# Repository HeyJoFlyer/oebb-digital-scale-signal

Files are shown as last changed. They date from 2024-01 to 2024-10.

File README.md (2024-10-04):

# ÖBB digital HV signal

## Description
This is an open-source project that provides detailed instructions for 
creating a 3D printed ÖBB (Austrian Federal Railways) signal model based 
on the [3d model](https://www.thingiverse.com/thing:6121234/files) of [Stubenflieger](https://www.thingiverse.com/stubenflieger/designs).

signal photo

## Features
- 3D printed model
- Multicolor sign
- Based on the work of Stubenflieger
- All signal states implemented in software
- G-Scale model, also useable as decoration

## Requirements
To create the ÖBB signal, you will need:
1. A 3D printer with the appropriate capabilities (multicolor not required, but helps for `4_Hauptsignal_Platte multicolor.3mf`)
1. 12 5mm leds: (5 green, 3 yellow, 1 red, 3 white)
1. Raspberry Pi Pico with [Circuitpython](https://circuitpython.org/board/raspberry_pi_pico/) (no extra libraries)
1. Resistors and wires and 2 buttons

## Instructions
1. Print 3d models, you can choose to print 
1. if you dont have the required color or dont have a multicolor 3d printer, you should paint the parts (photos), you can view the renders [here](/renders/renders.md).
1. Assembly parts (I used a 3d pen with same grey filament)
1. Under `test/code.py`you can find a test python script, where you will need to adjust the GP pins to your connected pins. With this script you can figure out which led is connected to which pin (took me ages without it), you can switch active led by pulling `GP0` low. You can view the output on the `REPL`using Thonny or MU editor.

## Acknowledgments
This open source project is based on the [work of Stubenflieger](https://www.thingiverse.com/thing:6121234/files).

## License
This project is licensed under the CC-BY-NC-4.0 License (as was Stubenfliegers design), following files are also available under the MIT License:
- `code.py`
- `test/cody.py`

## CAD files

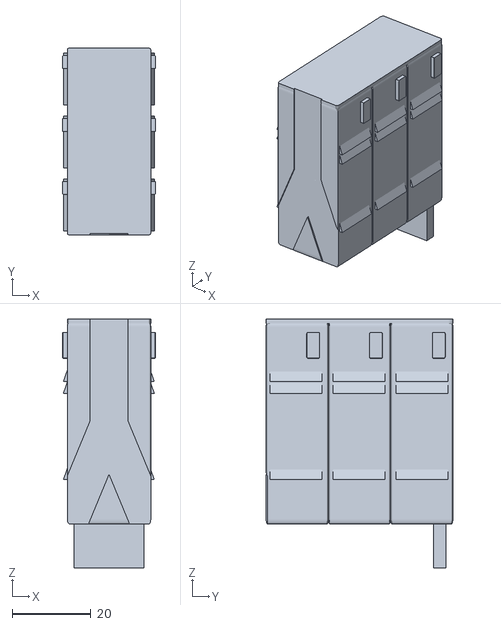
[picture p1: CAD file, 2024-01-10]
3a_Signalbox_gross.stl
23.6 x 47.6 x 63.4

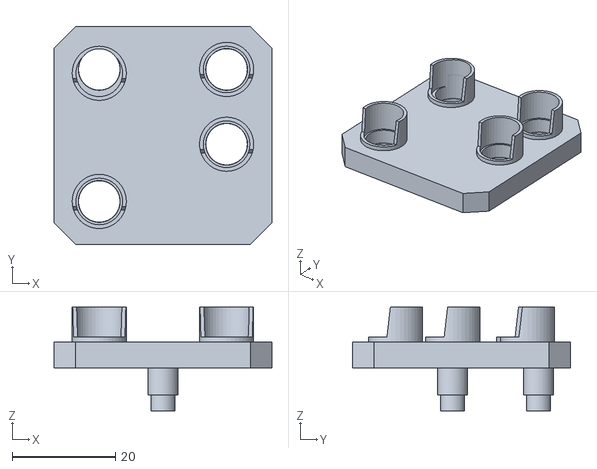
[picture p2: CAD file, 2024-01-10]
Vor_Signal_Spur_G.stl
42.2 x 42.2 x 20.1

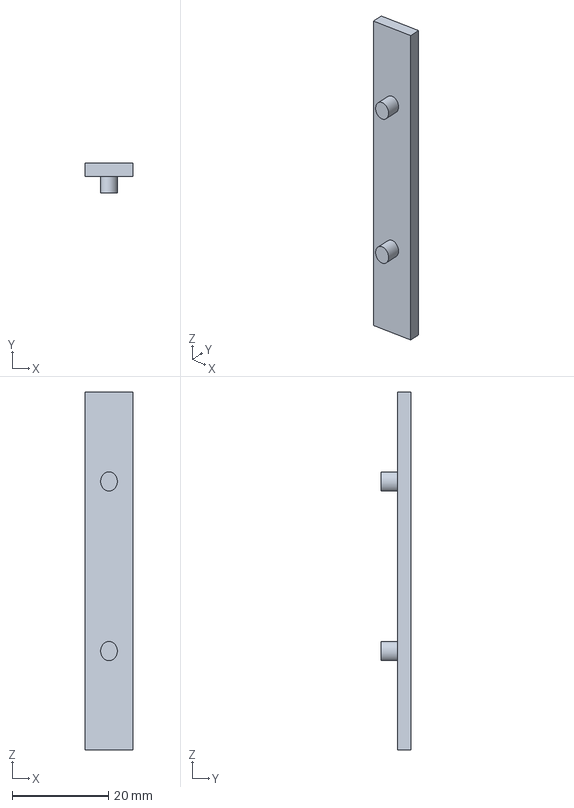
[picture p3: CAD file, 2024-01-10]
4_Hauptsignal_Platte multicolor.3mf
10.0 x 6.13 x 74.3 mm

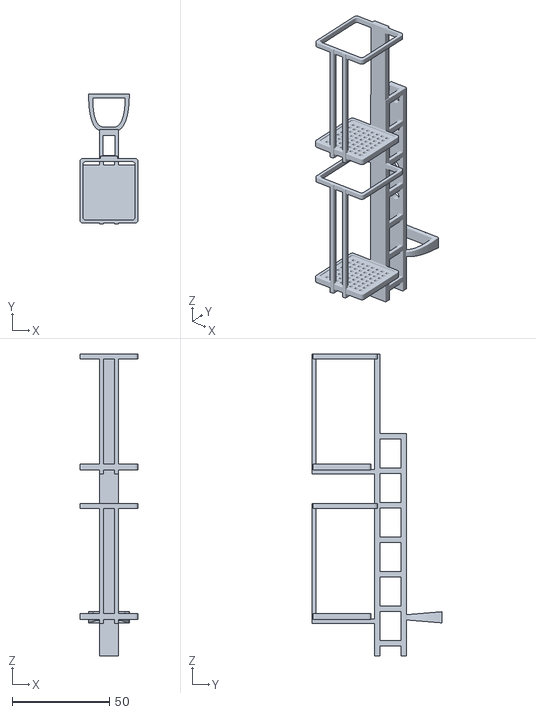
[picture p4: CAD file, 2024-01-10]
2a_Haupt_Vor_Signal_Spur_G_Mast_oben.stl
30.0 x 67.0 x 155.6

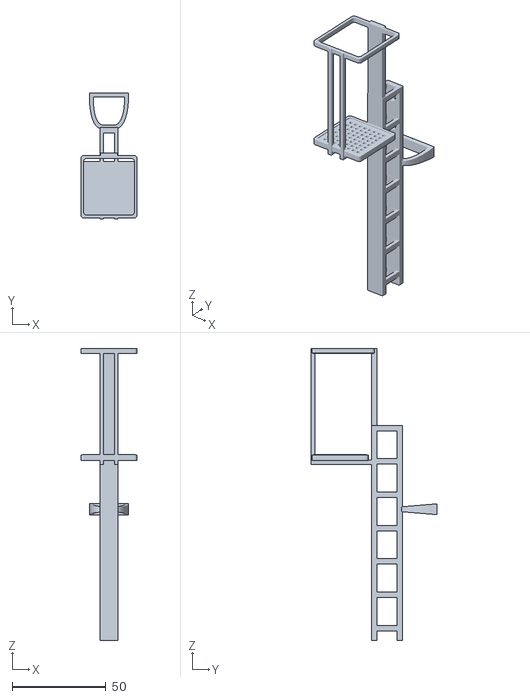
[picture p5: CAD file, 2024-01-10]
2b_Haupt_Signal_Spur_G_Mast_oben.stl
30.0 x 67.0 x 155.6

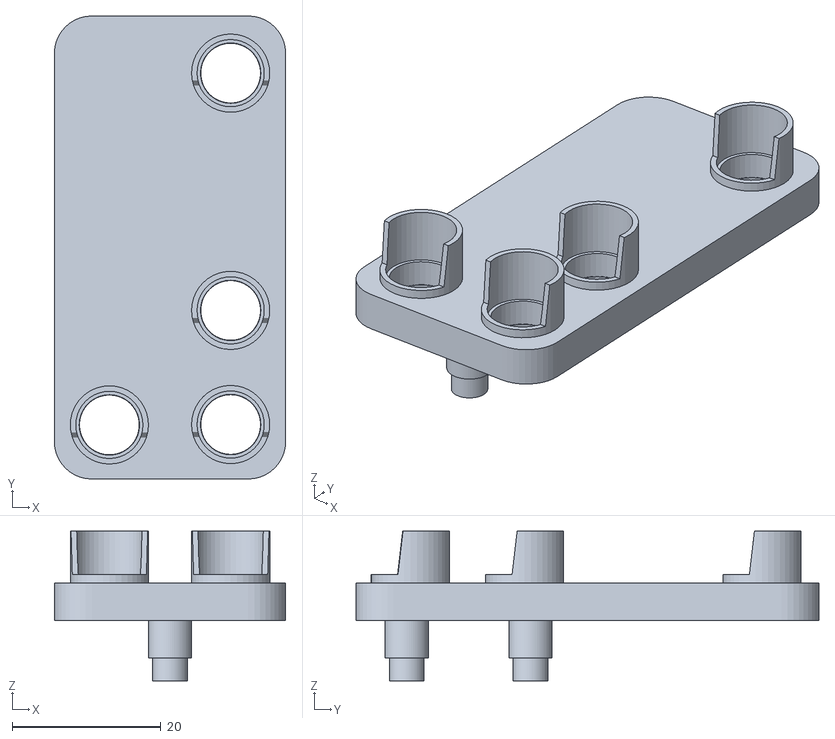
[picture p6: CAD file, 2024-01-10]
Hauptsignal_grosse_Lampen_Spur_G.stl
31.1 x 62.2 x 20.1

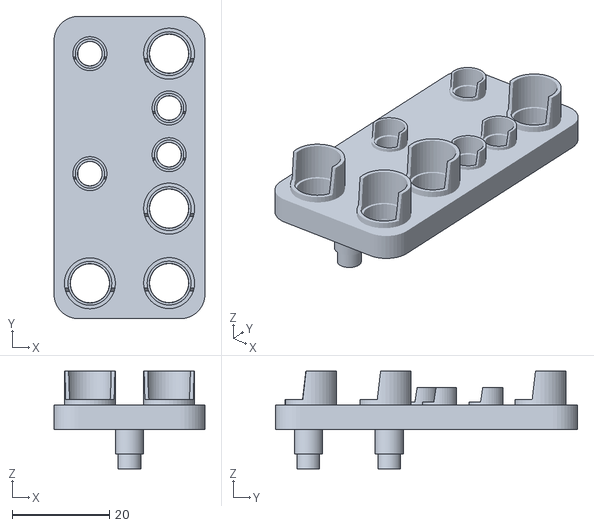
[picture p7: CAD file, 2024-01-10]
Hauptsignal_komplett_Spur_G.stl
31.1 x 62.2 x 20.1

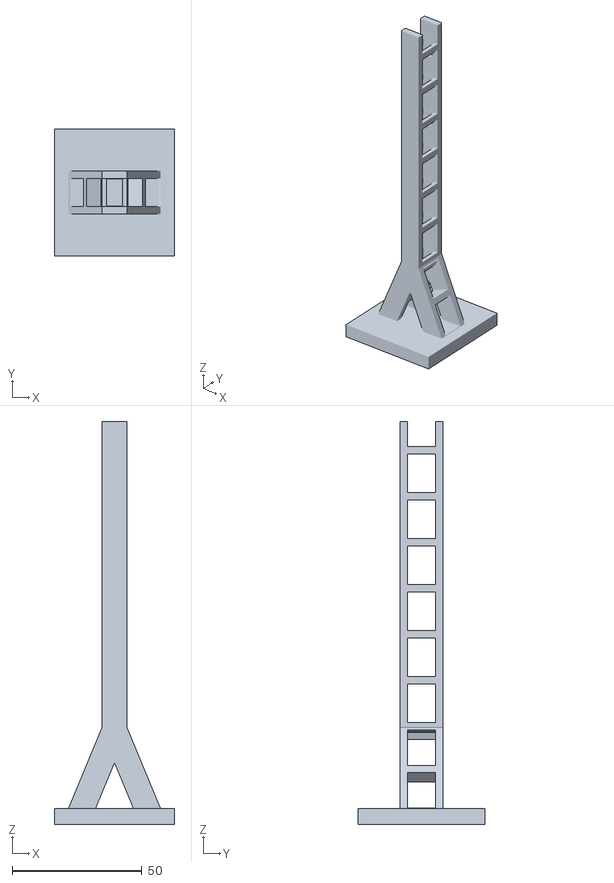
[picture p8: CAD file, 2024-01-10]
1_Haupt_Vor_Signal_Spur_G_Mast_unten.stl
46.4 x 49.1 x 155.6

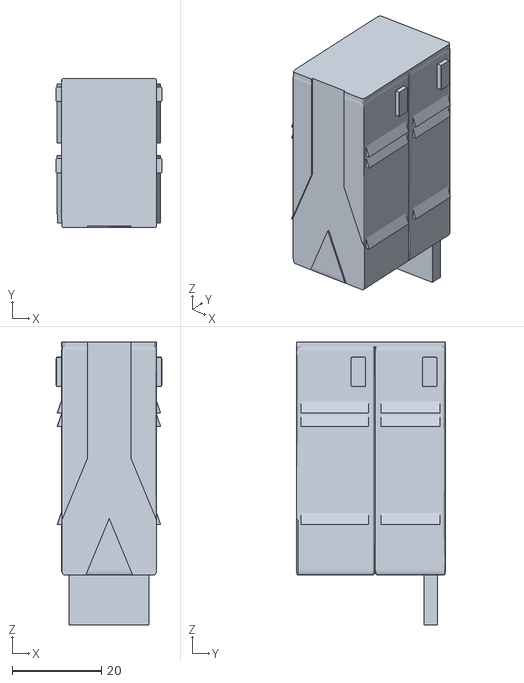
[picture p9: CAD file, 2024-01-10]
3b_Signalbox_klein.stl
23.6 x 33.5 x 63.4

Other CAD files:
4_Hauptsignal_Platte orig.stl

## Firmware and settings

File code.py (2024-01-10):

# SPDX-FileCopyrightText: 2024 Nico Gartner
#
# SPDX-License-Identifier: MIT
import board
import time
from digitalio import DigitalInOut, Direction, Pull

right_yellow_light = DigitalInOut(board.GP14)
left_yellow_light = DigitalInOut(board.GP12)
right_green_light = DigitalInOut(board.GP20)
left_green_light = DigitalInOut(board.GP18)

hp1_green_light = DigitalInOut(board.GP26)
hp2_green_light = DigitalInOut(board.GP13)
hp2_yellow_light = DigitalInOut(board.GP22)
hp0_red_light = DigitalInOut(board.GP17)
depature_green_light = DigitalInOut(board.GP19)
upper_white_light = DigitalInOut(board.GP15)
lower_white_light = DigitalInOut(board.GP21)
right_white_light = DigitalInOut(board.GP16)

right_yellow_light.direction = Direction.OUTPUT
left_yellow_light.direction = Direction.OUTPUT
right_green_light.direction = Direction.OUTPUT
left_green_light.direction = Direction.OUTPUT

hp1_green_light.direction = Direction.OUTPUT
hp2_green_light.direction = Direction.OUTPUT
hp2_yellow_light.direction = Direction.OUTPUT
hp0_red_light.direction = Direction.OUTPUT
depature_green_light.direction = Direction.OUTPUT
upper_white_light.direction = Direction.OUTPUT
lower_white_light.direction = Direction.OUTPUT
right_white_light.direction = Direction.OUTPUT

right_yellow_light.value = False
left_yellow_light.value = False
right_green_light.value = False
left_green_light.value = False

hp1_green_light.value = False
hp2_green_light.value = False
hp2_yellow_light.value = False
hp0_red_light.value = False
depature_green_light.value = False
upper_white_light.value = False
lower_white_light.value = False
right_white_light.value = False

button = DigitalInOut(board.GP0)
button.direction = Direction.INPUT
button.pull = Pull.UP

button_vor = DigitalInOut(board.GP1)
button_vor.direction = Direction.INPUT
button_vor.pull = Pull.UP

# (0, 0, 0, 0, 0, 0, 0, 0)
# (0, 0, 0, 0)

signalbegriffe = {"halt": (0, 0, 0, 1, 0, 0, 0, 0), "frei": (1, 0, 0, 0, 0, 0, 0, 0), "frei 60": (1, 1, 0, 0, 0, 0, 0, 0), "frei 40": (1, 0, 1, 0, 0, 0, 0, 0), "fahrverbot aufgehoben": (0, 0, 0, 0, 0, 1, 1, 0), "verschubverbot aufgehoben": (0, 0, 0, 1, 0, 0, 1, 1), "abfahren erlaubt": (1, 0, 0, 0, 2, 0, 0, 0), "ersatzsignal": (0, 0, 0, 1, 0, 2, 0, 0)}
vorsignalbegriffe = {"vorsicht": (1, 1, 0, 0), "hautpsignal frei": (0, 0, 1, 1), "hautpsignal frei 60": (0, 1, 1, 1), "hautpsignal frei 40": (1, 1, 0, 1), "abgeschaltet": (0, 0, 0, 0)}
signalbegriffe_keys = list(signalbegriffe.keys())
vorsignalbegriffe_keys = list(vorsignalbegriffe.keys())

def signal(signalbegriff_index, vorsignalbegriff_index):
    j = signalbegriffe_keys[signalbegriff_index]
    values = signalbegriffe[j]
    k = vorsignalbegriffe_keys[vorsignalbegriff_index]
    print(j, k)
    values_vor = vorsignalbegriffe[k]
    to_blink = []
    if values[0] == 1:
        hp1_green_light.value = True
    elif values[0] == 2:
        to_blink.append(hp1_green_light)
    else:
        hp1_green_light.value = False
    
    if values[1] == 1:
        hp2_green_light.value = True
    elif values[1] == 2:
        to_blink.append(hp2_green_light)
    else:
        hp2_green_light.value = False
    
    if values[2] == 1:
        hp2_yellow_light.value = True
    elif values[2] == 2:
        to_blink.append(hp2_yellow_light)
    else:
        hp2_yellow_light.value = False

    if values[3] == 1:
        hp0_red_light.value = True
    elif values[3] == 2:
        to_blink.append(hp0_red_light)
    else:
        hp0_red_light.value = False

    if values[4] == 1:
        depature_green_light.value = True
    elif values[4] == 2:
        to_blink.append(depature_green_light)
    else:
        depature_green_light.value = False

    if values[5] == 1:
        upper_white_light.value = True
    elif values[5] == 2:
        to_blink.append(upper_white_light)
    else:
        upper_white_light.value = False

    if values[6] == 1:
        lower_white_light.value = True
    elif values[6] == 2:
        to_blink.append(lower_white_light)
    else:
        lower_white_light.value = False

    if values[7] == 1:
        right_white_light.value = True
    elif values[7] == 2:
        to_blink.append(right_white_light)
    else:
        right_white_light.value = False

    if values_vor[0] == 1:
        right_yellow_light.value = True
    elif values_vor[0] == 2:
        to_blink.append(right_yellow_light)
    else:
        right_yellow_light.value = False

    if values_vor[1] == 1:
        left_yellow_light.value = True
    elif values_vor[1] == 2:
        to_blink.append(left_yellow_light)
    else:
        left_yellow_light.value = False

    if values_vor[2] == 1:
        right_green_light.value = True
    elif values_vor[2] == 2:
        to_blink.append(right_green_light)
    else:
       right_green_light.value = False

    if values_vor[3] == 1:
        left_green_light.value = True
    elif values_vor[3] == 2:
        to_blink.append(left_green_light)
    else:
        left_green_light.value = False
    return to_blink

old_time = time.time()
old_time_vor = time.time()
old_animation_time = time.time()
signalbegriffe_index = 0
vorsignalbegriffe_index = 0
animation_list = []
on = False

signal(signalbegriffe_index, vorsignalbegriffe_index)

while True:
    time.sleep(0.01)
    if button.value == False and time.time() - old_time > 0.4:
        old_time = time.time()
        signalbegriffe_index += 1
        if signalbegriffe_index > len(signalbegriffe) - 1:
            signalbegriffe_index = 0
        animation_list = signal(signalbegriffe_index, vorsignalbegriffe_index)

    if button_vor.value == False and time.time() - old_time_vor > 0.4:
        old_time_vor = time.time()
        vorsignalbegriffe_index += 1
        if vorsignalbegriffe_index > len(vorsignalbegriffe) - 1:
            vorsignalbegriffe_index = 0
        animation_list = signal(signalbegriffe_index, vorsignalbegriffe_index)   

    if time.time() - old_animation_time > 1:
        old_animation_time = time.time()
        for light in animation_list:
            light.value = on
        on = not on

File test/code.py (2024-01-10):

# SPDX-FileCopyrightText: 2024 Nico Gartner
#
# SPDX-License-Identifier: MIT
import board
import time
from digitalio import DigitalInOut, Direction, Pull

led1 = DigitalInOut(board.GP14)
led2 = DigitalInOut(board.GP21)
led3 = DigitalInOut(board.GP18)
led4 = DigitalInOut(board.GP22)

led5 = DigitalInOut(board.GP26)
led6 = DigitalInOut(board.GP13)
led7 = DigitalInOut(board.GP12)
led8 = DigitalInOut(board.GP20)
led9 = DigitalInOut(board.GP19)
led10 = DigitalInOut(board.GP15)
led11 = DigitalInOut(board.GP17)
led12 = DigitalInOut(board.GP16)

led1.direction = Direction.OUTPUT
led2.direction = Direction.OUTPUT
led3.direction = Direction.OUTPUT
led4.direction = Direction.OUTPUT

led5.direction = Direction.OUTPUT
led6.direction = Direction.OUTPUT
led7.direction = Direction.OUTPUT
led9.direction = Direction.OUTPUT
led9.direction = Direction.OUTPUT
led10.direction = Direction.OUTPUT
led11.direction = Direction.OUTPUT
led12.direction = Direction.OUTPUT

button = DigitalInOut(board.GP0)
button.direction = Direction.INPUT
button.pull = Pull.UP
old_time = time.time()

pins = []
for i in range(12):
    pins.append(f"led{i + 1}")
index = 0

while True:
    if button.value == True and time.time() - old_time > 1:
        old_time = time.time()
        index += 1
        if index > len(pins) - 1:
            index = 0
        print(pins[index])
        if pins[index] == "led1":
            led1.value = True
        else:
            led1.value = False
        if pins[index] == "led2":
            led2.value = True
        else:
            led2.value = False
        if pins[index] == "led3":
            led3.value = True
        else:
            led3.value = False
        if pins[index] == "led4":
            led4.value = True
        else:
            led4.value = False
        if pins[index] == "led5":
            led5.value = True
        else:
            led5.value = False
        if pins[index] == "led6":
            led6.value = True
        else:
            led6.value = False
        if pins[index] == "led7":
            led7.value = True
        else:
            led7.value = False
        if pins[index] == "led8":
            led8.value = True
        else:
            led8.value = False
        if pins[index] == "led9":
            led9.value = True
        else:
            led9.value = False
        if pins[index] == "led10":
            led10.value = True
        else:
            led10.value = False
        if pins[index] == "led11":
            led11.value = True
        else:
            led11.value = False
        if pins[index] == "led12":
            led12.value = True
        else:
            led12.value = False
